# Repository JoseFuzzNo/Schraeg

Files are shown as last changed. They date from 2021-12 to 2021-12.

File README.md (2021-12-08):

# Schräg

Schräg is an 8HP multimode filter module for the eurorack format, based off the [Bastl Cinnamon](https://bastl-instruments.com/eurorack/modules/cinnamon).

This is a rework of the original [Schräg](https://github.com/barnabywalters/Schraeg) by Barnaby Walters.

<p align="center">
    
</p>

## Quick links

* [Schematic](pcb/schraeg.pdf)
* [Gerbers](gerbers/schraeg-gerbers-0.4.zip)
* [BOM](bom/schraeg_BOM.xlsx)
* [Schräg on ModularGrid](https://www.modulargrid.net/e/other-unknown-f1no5-schraeg)

## Features

Schräg is effectively a repackaged Bastl Cinnamon:

* Multimode filter with independent outputs (2-pole LP, 2-pole HP, 1-pole BP)
* V/oct input
* Self-resonates for use as a sine oscillator
* Input with an attenuator and 5x gain switch
* Two character switches for altering the resonance tracking
* All-SMD construction in a DIY-friendly format, with 0603 handsoldering footprints, all components on the back of the circuit board
* Built mostly using standard and easily-available components

with a few modifications:

* Larger 8HP form factor, allowing for a big juicy cutoff knob and larger character and gain switches
* Voltage control over resonance, through an attenuverter
* FM input through an attenuverter, which works as a pitch fine-tune control with nothing patched
* A bi-directional power connector, with polyfuses
* An Interactive BOM (`bom/schraeg_iBOM.html` once you’ve cloned the repo locally) to aid in part placement
* Schematics and PCB laid out using KiCAD

The additional functionality is achieved with a minimum of extra components, thanks to the two unused VCA cells in the original design.

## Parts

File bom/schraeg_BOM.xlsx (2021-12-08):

SCHRÄG, v0.4.0
Designator | Description | Package | Specs | Qty | Value | Manufacturer | Reference | Ref. Mouser
SMD Parts: 84 pcs
C3,C9 | Capacitor, ceramic | 0603 |  | 2 | 100p | Yageo | CC603GPNPO9BN101 | 603-CC603GPNPO9BN101
C10,C11,C13 | Capacitor, ceramic | 0603 |  | 3 | 220p | Yageo | CC603JRX7R9BB221 | 603-CC603JRX7R9BB221
C1,C7,C8,C12 | Capacitor, ceramic | 0603 |  | 4 | 560p | Yageo | CC603JRNPO8BN561 | 603-CC603JRNPO8BN561
C14,C15,C19,C20,C21,C22,C23,C24,C25,C26,C27,C28 | Capacitor, ceramic | 0603 | >= 25V | 10 | 100n | Yageo | CC0603MR9BB104 | 603-CC0603MR9BB104
C2,C4,C5,C6 | Capacitor, electrolytic | 5x4.5 |  | 4 | 10u | Panasonic | EEE-FC1V100R | 667-EEE-FC1V100R
C16,C17 | Capacitor, electrolytic | 6.3x5.4 | >= 25V | 2 | 22u | Panasonic | EEE-FC1E220AP | 667-EEE-FC1E220AP
D1,D2,D4 | Diode, general purpose | SOD-123 |  | 3 |  | Diodes Inc | 1N4148W-7-F | 621-1N4148W-F
D3 | Diode, zener | SOT-23-3 | 5V | 1 |  | Nexperia | PLVA650A,215 | 771-PLVA650A-T/R
D5 | Full bridge rectifier | SO-4 |  | 1 |  | OnSemi | MB1S | 512-MB1S
F1,F2 | PTC Fuse | 1206 |  | 2 |  | Bourns | MF-NSMF050-2 | 652-MF-NSMF050-2
R44 | Resistor, 1% | 0603 |  | 1 | 220R | Panasonic | ERJ-3EKF2200V | 667-ERJ-3EKF2200V
R15,R30,R32,R39 | Resistor, 1% | 0603 |  | 4 | 470R | Panasonic | ERJ-3EKF4700V | 667-ERJ-3EKF4700V
R23,R24,R25 | Resistor, 1% | 0603 |  | 3 | 1K | Panasonic | ERJ-3EKF1001V | 667-ERJ-3EKF1001V
R41 | Resistor, 1% | 0603 |  | 1 | 1K5 | Panasonic | ERJ-3EKF1501V | 667-ERJ-3EKF1501V
R21 | Resistor, 1% | 0603 |  | 1 | 10K | Panasonic | ERJ-3EKF1002V | 667-ERJ-3EKF1002V
R14,R40 | Resistor, 1% | 0603 |  | 2 | 15K | Panasonic | ERJ-3EKF1502V | 667-ERJ-3EKF1502V
R18 | Resistor, 1% | 0603 |  | 1 | 22K | Panasonic | ERJ-3EKF2202V | 667-ERJ-3EKF2202V
R27,R28,R29,R31,R33,R34,R35,R36,R38 | Resistor, 1% | 0603 |  | 9 | 33K | Panasonic | ERJ-3EKF3302V | 667-ERJ-3EKF3302V
R19,R22 | Resistor, 1% | 0603 |  | 2 | 47K | Panasonic | ERJ-3EKF4702V | 667-ERJ-3EKF4702V
R8 | Resistor, 1% | 0603 |  | 1 | 56K | Panasonic | ERJ-3EKF5602V | 667-ERJ-3EKF5602V
R1,R2,R3,R4,R5,R6,R7,R9,R10,R13,R16,R17,R20,R37,R42,R48,R49 | Resistor, 1% | 0603 |  | 17 | 100K | Panasonic | ERJ-3EKF1003V | 667-ERJ-3EKF1003V
R12 | Resistor, 1% | 0603 |  | 1 | 220K | Panasonic | ERJ-3EKF2203V | 667-ERJ-3EKF2203V
R26 | Resistor, 1% | 0603 |  | 1 | 330K | Panasonic | ERJ-3EKF3303V | 667-ERJ-3EKF3303V
R43 | Resistor, 1% | 0603 |  | 1 | 470K | Panasonic | ERJ-3EKF4703V | 667-ERJ-3EKF4703V
R11 | Resistor, 1% | 0603 |  | 1 | 2M2 | Panasonic | ERJ-3EKF2204V | 667-ERJ-3EKF2204V
U1,U2,U4,U5 | Quad op-amp | TSSOP-14 |  | 4 |  | Texas Instruments | TL074CPWR | 595-TL074CPWR
U3 | Quad VCA | SOIC-16 |  | 1 |  | Cool Audio | V2164
U6 | Single op-amp | SOT-23-5 |  | 1 |  | Texas Instruments | LM321MFX/NOPB | 926-LM321MFX/NOPB
THT Parts: 20 pcs
D6 | LED, red, 5mm | T-1 3/4 |  | 1 |  | Kingbright | WP483IDT | 604-WP483IDT
J1,J2,J3,J4,J5,J6,J7 | Vertical jack connector |  |  | 7 |  | QingPu | PJ398SM
J8 | 2x5 male header, 2.54mm pitch |  |  | 1 |  | Amphenol FCI | 67996-410HLF | 649-67996-410HLF
RV1,RV2,RV3,RV4 | 100K linear pot, 25mm shaft with marker |  |  | 4 | 100K | Song Huei
RV5 | 100K linear pot, 15mm shaft |  |  | 1 | 100KB | Alpha
RV6 | Multiturn trimmer pot |  |  | 1 | 100K | Bourns | 3266Y-1-104LF | 652-3266Y-1-104LF
RV7 | Multiturn trimmer pot |  |  | 1 | 5K | Bourns | 3266Y-1-502LF | 652-3266Y-1-502LF
RV8 | Multiturn trimmer pot |  |  | 1 | 250K | Bourns | 3266Y-1-254LF | 652-3266Y-1-254LF
SW1,SW2,SW3 | Slide switch SPDT |  |  | 3 |  | NKK Switches | CS12ANW03 | 633-CS12ANW03

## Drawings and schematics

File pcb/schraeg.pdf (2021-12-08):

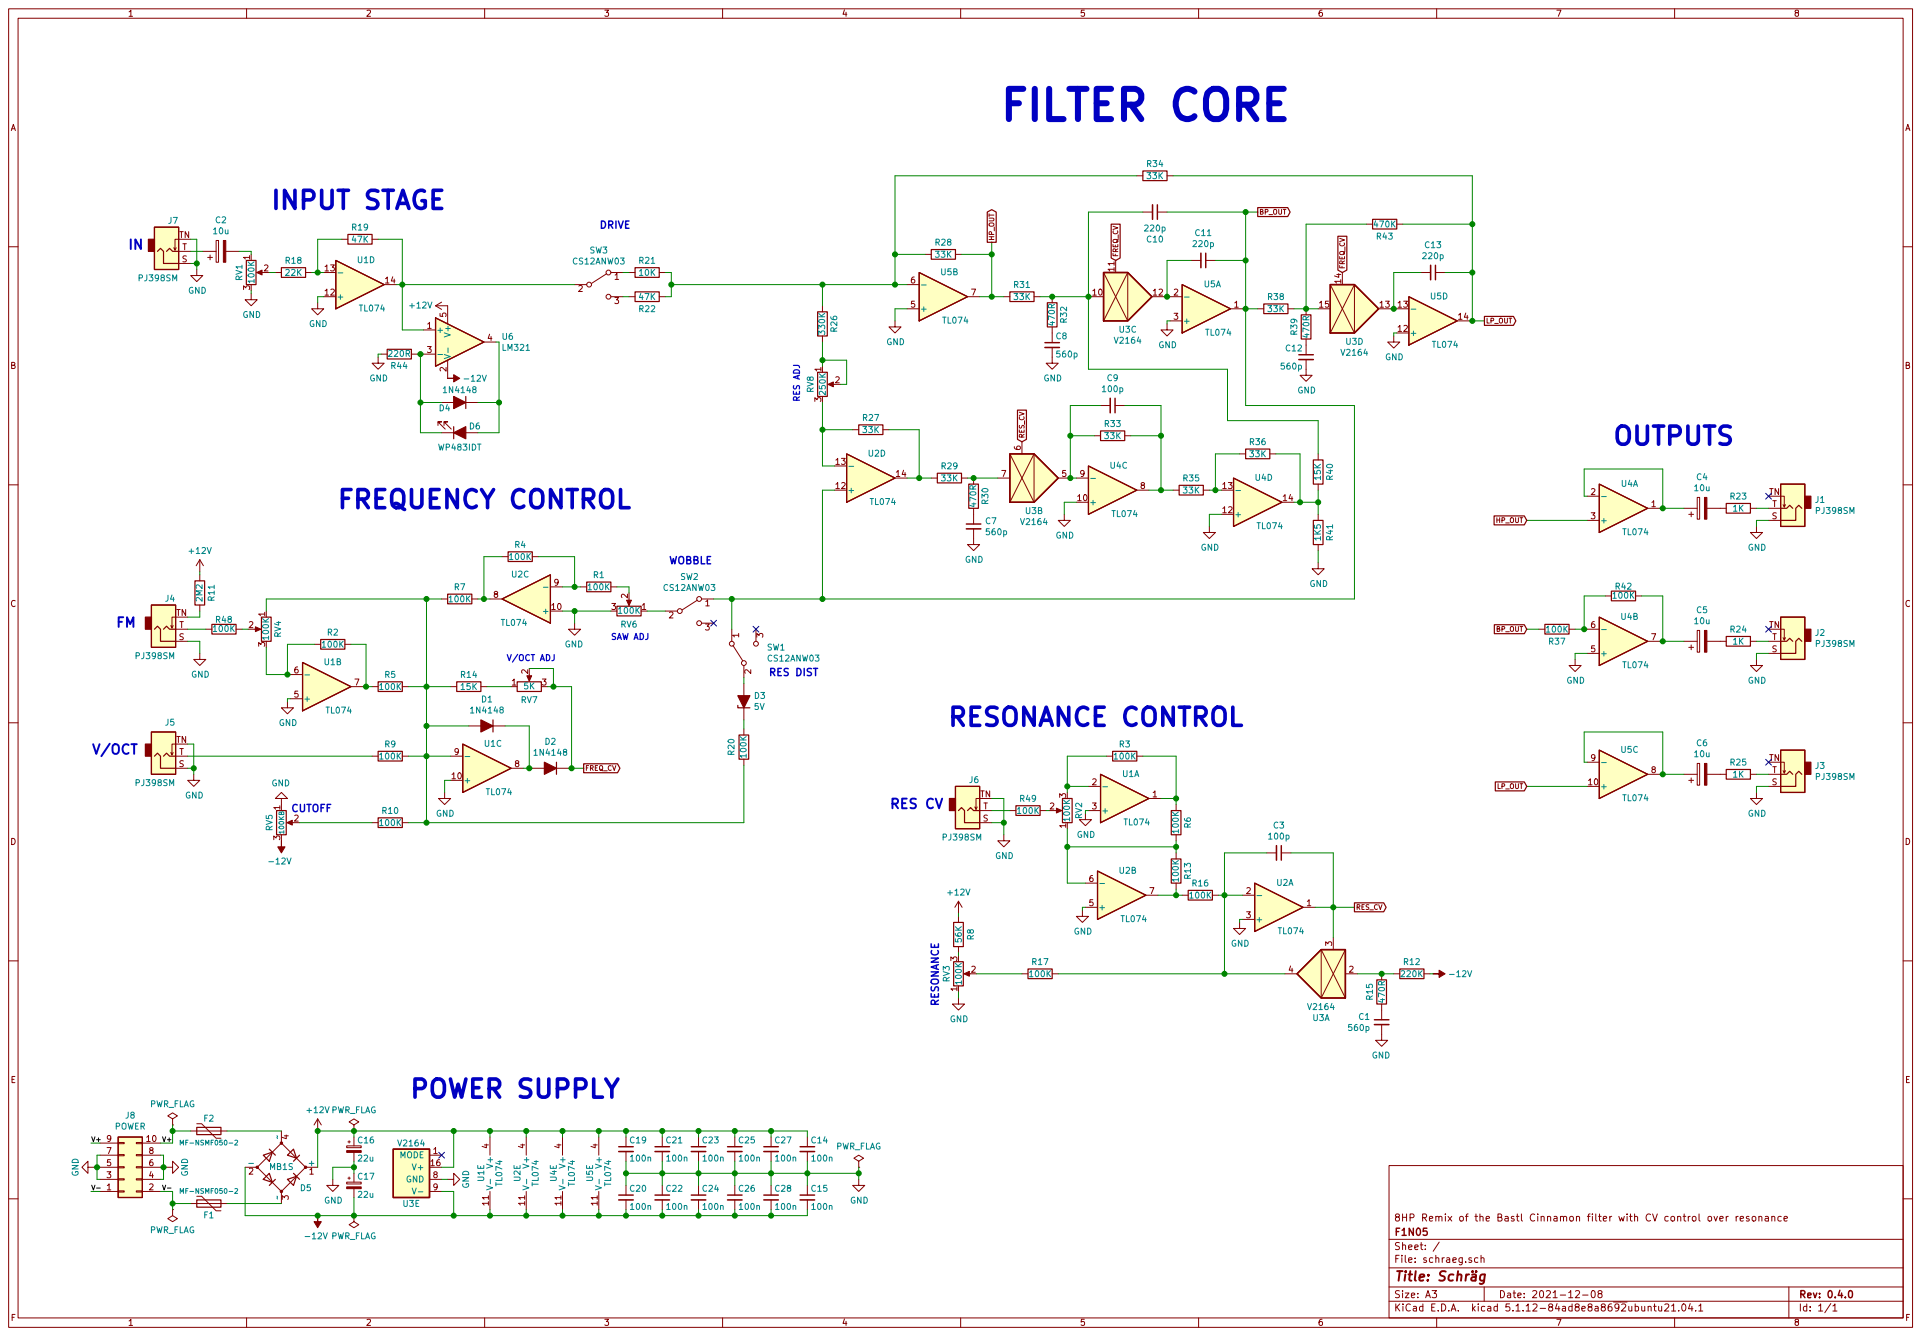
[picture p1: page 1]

8HP Remix of the Bastl Cinnamon filter with CV control over resonance
File: schraeg.sch Sheet: / F1N05

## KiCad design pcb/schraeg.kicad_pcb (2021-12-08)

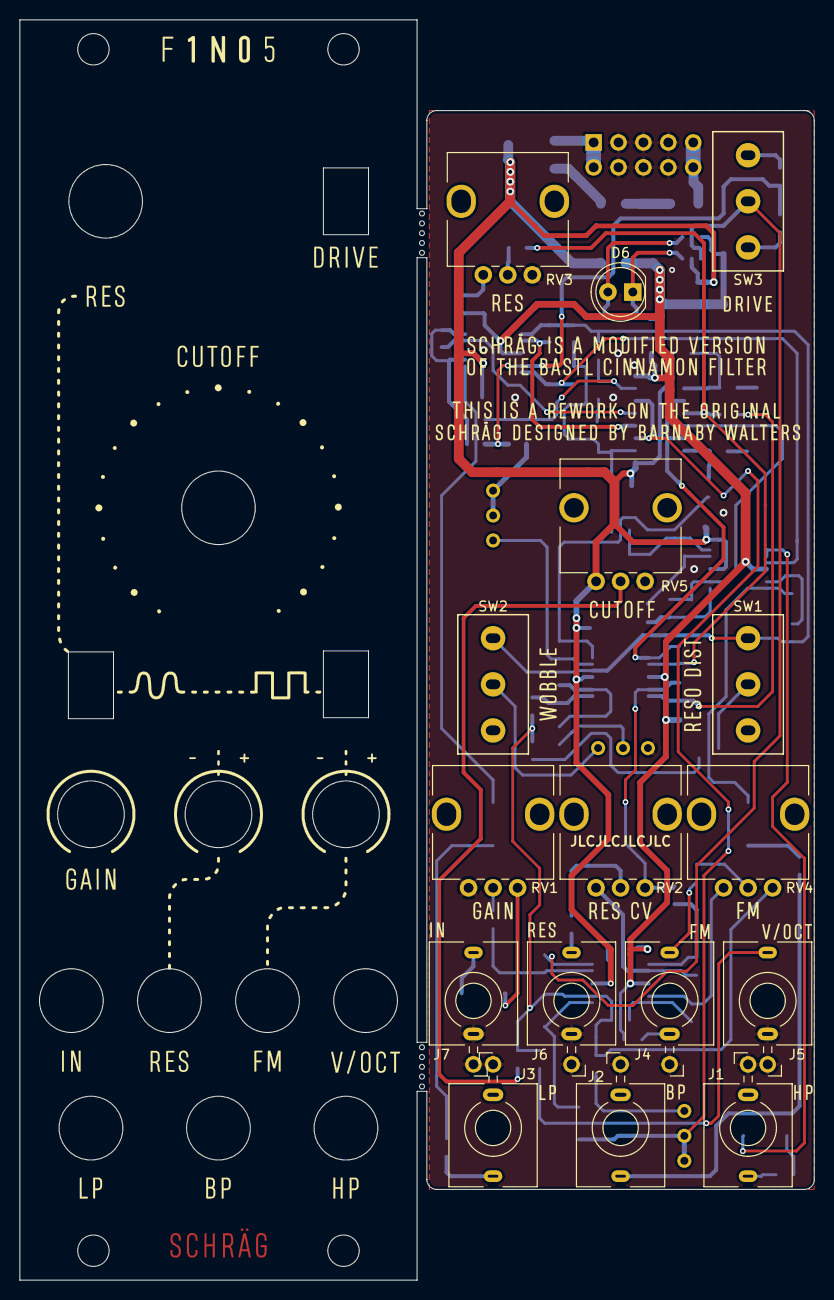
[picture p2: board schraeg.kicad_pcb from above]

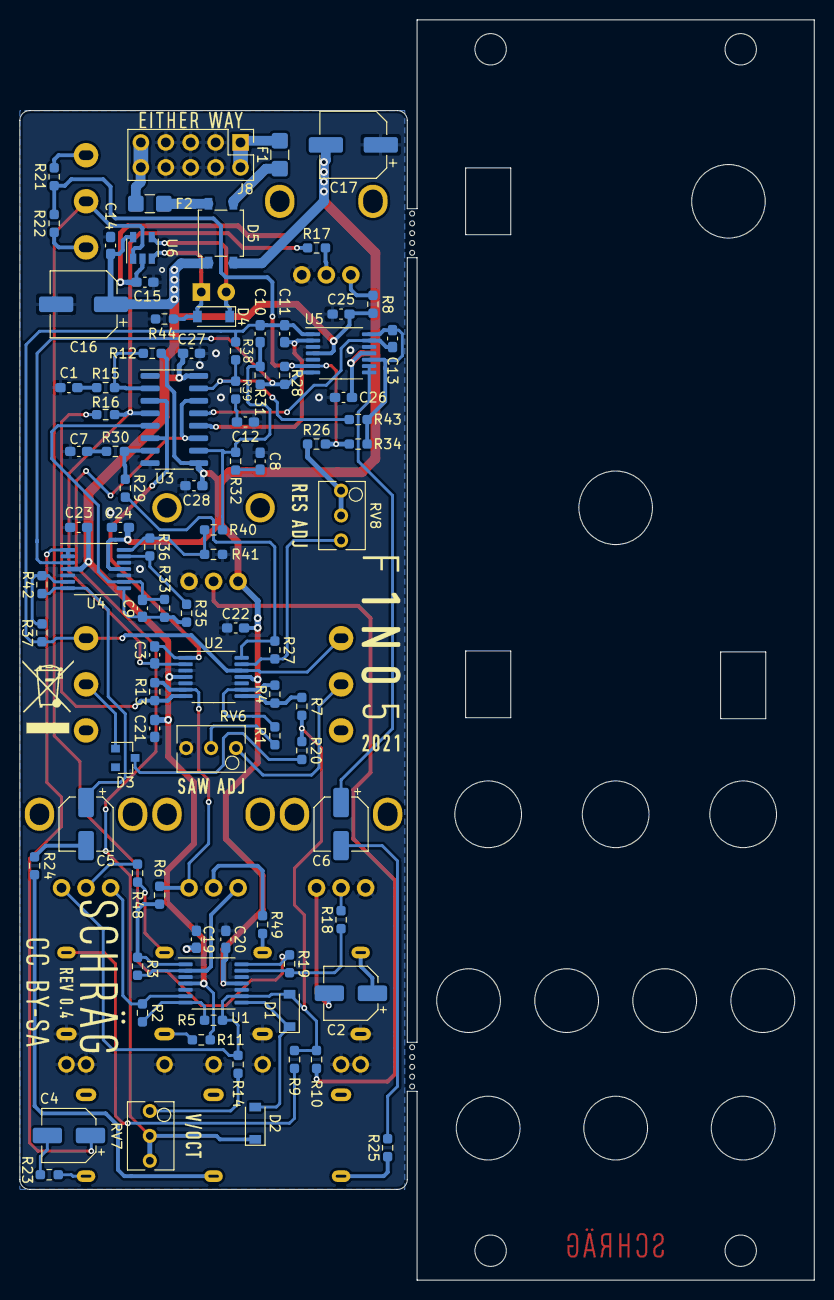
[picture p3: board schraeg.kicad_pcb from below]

Board: 2 copper layers, 81.0 x 128.5 mm, 106 parts (90 on the bottom side), 74 nets.

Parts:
C1, C7, C8, C12: 560p; C_0603_1608Metric_Pad1.08x0.95mm_HandSolder
C2, C4, C5, C6: 10u; CP_Elec_5x4.5
C3, C9: 100p; C_0603_1608Metric_Pad1.08x0.95mm_HandSolder
C10, C11, C13: 220p; C_0603_1608Metric_Pad1.08x0.95mm_HandSolder
C14, C15, C19, C20, C21, C22, C23, C24, C25, C26, C27, C28: 100n; C_0603_1608Metric_Pad1.08x0.95mm_HandSolder
C16, C17: 22u; CP_Elec_6.3x5.4
D1, D2, D4: 1N4148; D_SOD-123
D3: 5V; D_SOT-23_ANK
D5: MB1S; SO-4_4.4x4.3mm_P2.54mm
D6: WP483IDT; LED_D5.0mm
F1, F2: MF-NSMF050-2; Fuse_1206_3216Metric_Castellated
J1, J2, J3, J4, J5, J6, J7: PJ398SM; Jack_3.5mm_QingPu_WQP-PJ398SM_Vertical_CircularHoles
J8: POWER; PinHeader_2x05_P2.54mm_Vertical
R1, R2, R3, R4, R5, R6, R7, R9, R10, R13, R16, R17, R20, R37, R42, R48, R49: 100K; R_0603_1608Metric_Pad0.98x0.95mm_HandSolder
R8: 56K; R_0603_1608Metric_Pad0.98x0.95mm_HandSolder
R11: 2M2; R_0603_1608Metric_Pad0.98x0.95mm_HandSolder
R12: 220K; R_0603_1608Metric_Pad0.98x0.95mm_HandSolder
R14, R40: 15K; R_0603_1608Metric_Pad0.98x0.95mm_HandSolder
R15, R30, R32, R39: 470R; R_0603_1608Metric_Pad0.98x0.95mm_HandSolder
R18: 22K; R_0603_1608Metric_Pad0.98x0.95mm_HandSolder
R19, R22: 47K; R_0603_1608Metric_Pad0.98x0.95mm_HandSolder
R21: 10K; R_0603_1608Metric_Pad0.98x0.95mm_HandSolder
R23, R24, R25: 1K; R_0603_1608Metric_Pad0.98x0.95mm_HandSolder
R26: 330K; R_0603_1608Metric_Pad0.98x0.95mm_HandSolder
R27, R28, R29, R31, R33, R34, R35, R36, R38: 33K; R_0603_1608Metric_Pad0.98x0.95mm_HandSolder
R41: 1K5; R_0603_1608Metric_Pad0.98x0.95mm_HandSolder
R43: 470K; R_0603_1608Metric_Pad0.98x0.95mm_HandSolder
R44: 220R; R_0603_1608Metric_Pad0.98x0.95mm_HandSolder
RV1, RV2, RV3, RV4: 100K; Potentiometer_Trimmer_9mm_Vertical
RV5: 100KB; Potentiometer_Alps-Alpha-Bourns_Single_Vertical
RV6: 100K; Potentiometer_Bourns_3266Y_Vertical
RV7: 5K; Potentiometer_Bourns_3266Y_Vertical
RV8: 250K; Potentiometer_Bourns_3266Y_Vertical
SW1, SW2, SW3: CS12ANW03; SW_NKK_CS1xA
U1, U2, U4, U5: TL074; TSSOP-14_4.4x5mm_P0.65mm
U3: V2164; SOIC-16_3.9x9.9mm_P1.27mm
U6: LM321; SOT-23-5

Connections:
+12V: C14.1, C16.1, C19.1, C21.1, C23.1, C25.1, C27.1, D5.1, R8.1, R11.2, U1.4, U2.4, U3.16, U4.4, U5.4, U6.5
-12V: C15.2, C17.2, C20.2, C22.2, C24.2, C26.2, C28.2, D5.2, R12.2, RV5.3, U1.11, U2.11, U3.9, U4.11, U5.11, U6.2
/V+: F2.2, J8.9, J8.10
/V-: F1.2, J8.1, J8.2
BP_OUT: C10.1, C11.1, R37.2, R38.2, SW1.1, SW2.1, U2.12, U5.1
FREQ_CV: D2.1, RV7.2, RV7.3, U3.11, U3.14
GND: C1.2, C7.2, C8.2, C12.2, C14.2, C15.1, C16.2, C17.1, C19.2, C20.1, C21.2, C22.1, C23.2, C24.1, C25.2, C26.1, C27.2, C28.1, J1.S, J2.S, J3.S, J4.S, J5.S, J5.TN, J6.S, J6.TN, J7.S, J7.TN, J8.3, J8.4, J8.5, J8.6, J8.7, J8.8, R41.1, R44.1, RV1.3, RV3.1, RV5.1, RV6.3, U1.3, U1.5, U1.10, U1.12, U2.3, U2.5, U2.10, U3.8, U4.5, U4.10, U4.12, U5.3, U5.5, U5.12
HP_OUT: R28.1, R31.2, U4.3, U5.7
LP_OUT: C13.1, R34.1, R43.1, U5.10, U5.14
unnamed: C1.1, R15.1
unnamed: C2.1, J7.T
unnamed: C2.2, RV1.1
unnamed: C3.2, R16.1, R17.1, U2.2, U3.4
unnamed: C4.1, U4.1, U4.2
unnamed: C4.2, R23.2
unnamed: C5.1, R42.1, U4.7
unnamed: C5.2, R24.2
unnamed: C6.1, U5.8, U5.9
unnamed: C6.2, R25.2
unnamed: C7.1, R30.1
unnamed: C8.1, R32.1
unnamed: C9.1, R33.1, R35.2, U4.8
unnamed: C9.2, R33.2, U3.5, U4.9
unnamed: C10.2, R31.1, R32.2, R40.2, U3.10
unnamed: C11.2, U3.12, U5.2
unnamed: C12.1, R39.1
unnamed: C13.2, U3.13, U5.13
unnamed: D1.1, D2.2, U1.8
unnamed: D1.2, R5.1, R7.1, R9.1, R10.1, R14.2, R20.1, RV4.1, U1.9
unnamed: D3.1, R20.2
unnamed: D3.2, SW1.2
unnamed: D4.1, D6.2, U6.4
unnamed: D4.2, D6.1, R44.2, U6.3
unnamed: D5.3, F1.1
unnamed: D5.4, F2.1
unnamed: J1.T, R23.1
unnamed: J2.T, R24.1
unnamed: J3.T, R25.1
unnamed: J4.T, R48.1
unnamed: J4.TN, R11.1
unnamed: J5.T, R9.2
unnamed: J6.T, R49.2
unnamed: R1.1, R4.2, U2.9
unnamed: R1.2, RV6.2
unnamed: R2.1, R5.2, U1.7
unnamed: R2.2, RV4.3, U1.6
unnamed: R3.1, R6.1, U1.1
unnamed: R3.2, RV2.3, U1.2
unnamed: R4.1, R7.2, U2.8
unnamed: R8.2, RV3.3
unnamed: R10.2, RV5.2
unnamed: R12.1, R15.2, U3.2
unnamed: R13.1, R16.2, U2.7
unnamed: R6.2, R13.2, RV2.1, U2.6
unnamed: R14.1, RV7.1
unnamed: R17.2, RV3.2
unnamed: R18.1, R19.2, U1.13
unnamed: R18.2, RV1.2
unnamed: R19.1, SW3.2, U1.14, U6.1
unnamed: R21.1, R22.1, R26.2, R28.2, R34.2, U5.6
unnamed: R21.2, SW3.1
unnamed: R22.2, SW3.3
unnamed: R26.1, RV8.1, RV8.2
unnamed: R27.1, R29.2, U2.14
unnamed: R27.2, RV8.3, U2.13
unnamed: R29.1, R30.2, U3.7
unnamed: R35.1, R36.2, U4.13
unnamed: R36.1, R40.1, R41.2, U4.14
unnamed: R37.1, R42.2, U4.6
unnamed: R38.1, R39.2, R43.2, U3.15
unnamed: R48.2, RV4.2
unnamed: R49.1, RV2.2
unnamed: RV6.1, SW2.2
RES_CV: C3.1, U2.1, U3.3, U3.6

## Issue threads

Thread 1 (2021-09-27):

Fix FM Input range

JoseFuzzNo, 2021-09-27:

JoseFuzzNo, 2021-09-27:
Removed R8 because it was added to R5 or R48 and made a 200K gain resistor. Also R2, R5, and R48 are changed to 47K because we want a similar output swing that the cutoff control, that is 5V * (15K/47K).

Closed 2021-09-27.

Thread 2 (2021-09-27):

Fix RES CV range

JoseFuzzNo, 2021-09-27:

JoseFuzzNo, 2021-09-27:
As with the FM attenuverter, R11 was making the gain of the stage half of what it should. Removing that resistor we obtain a swing of -5 to 5V given a 5V input.

Closed 2021-09-27.

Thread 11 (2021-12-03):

LED indicator is not connected properly

JoseFuzzNo, 2021-12-03:
The LED stage is connected to the inverting input of U5B which is at 0V. This should be connected to the output of the input stage (U1D), before the gain resistor.

Closed 2021-12-08.

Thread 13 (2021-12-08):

FM range too wide

JoseFuzzNo, 2021-12-08:
FM range should be the same as V/OCT. Changing the 3 47K resistors for 100K solves the issue.

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

Closed 2021-12-08.

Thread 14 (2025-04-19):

Resonance control seems to not be under control

extremenerble, 2025-04-19:
Hello, first thanks for your work and publishing this design. Shot in the dark here that maybe you can point me in the right direction with some build help.

I put this module together and everything is working except the resonance is out of control. The Res knob doesn't really function, there's lots of resonance all the time. It seems to slightly change the character of the resonance with various combinations of the switches, but I can not take out resonance entirely. I'm using alpha pots for all the front panel controls (instead of tall trimmers), but that shouldn't have an effect, they're all  B100k.

I've verified continuity for all the components in the Resonance Control section of your schematic. The VCA chip is an SSI2164 sourced from Thonk. I have a spare 2164 but I haven't swapped it out yet.

Any ideas would be greatly appreciated!

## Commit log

2021-09-26 Added gitignore with kicad files
2021-09-26 Corrected alignment between panel and pcb, changed to slide switches, trimpot for resonance (leaves more space for cutoff) and new panel design.
    [Schraeg BOM.csv, Schraeg.kicad_pcb, Schraeg.sch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]
2021-09-26 Changed power symbol to generic connector
    [Schraeg.kicad_pcb, Schraeg.sch, power_supply.sch]
2021-09-26 V2164 symbol in a new library to avoid missing dependencies.
    [Schraeg.kicad_pcb, Schraeg.sch, filter_core.sch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]
2021-09-26 Cleaning and organizing the repo.
    [Schraeg Panel Graphics 40.64 x 128.5.dxf, Schraeg Panel Graphics.dxf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]
2021-09-27 #1 - Corrected FM atennuverter
    [Schraeg.kicad_pcb, Schraeg.sch]
2021-09-27 #2 - Corrected resonance attenuverter
    [Schraeg.kicad_pcb, Schraeg.sch]
2021-09-27 Changed paths to use Kicad variables
    [Schraeg.kicad_pcb]
2021-09-27 Consolidate names
    [filter_core.sch, power_supply.sch, schraeg.kicad_pcb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]
2021-09-27 #4 - Added mouser references
    [filter_core.sch, power_supply.sch, schraeg.kicad_pcb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]
2021-09-28 Tidy up
    [filter_core.sch, power_supply.sch, schraeg.kicad_pcb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]
2021-09-28 #5 - Removed 0.16V normalization to FM input.
    [schraeg.kicad_pcb, schraeg.sch]
2021-09-29 #4 - Added BOM with mouser references.
    [schraeg_BOM.csv, schraeg_BOM.xlsx]
2021-09-30 #6 - Replaced the 5V reference with a resistor divider. It should give a voltage of 5.1V.
    [schraeg.kicad_pcb, schraeg.sch, schraeg_BOM.xlsx]
2021-09-30 #7 - Removed the -5V reference. Changed R12 to have the same effect as before with -12V (-10.8V after the rectifier).
    [schraeg.kicad_pcb, schraeg.sch, schraeg_BOM.xlsx]
2021-10-04 New pcb distribution
    [schraeg.kicad_pcb, schraeg.sch, schraeg_BOM.xlsx]
2021-10-05 PCB Layout finished.
    [schraeg.kicad_pcb, schraeg.sch]
2021-10-05 BOM updated with smaller packages
    [schraeg_BOM.xlsx]
2021-10-05 Panel design on kicad and iBOM updated.
    [schraeg.kicad_pcb]
2021-10-06 Added silkscreen on PCB
    [schraeg.kicad_pcb]
2021-10-06 #8 - Added back the FM normalization. This time with a bit more than 1 OCT range.
    [schraeg.kicad_pcb, schraeg.sch, schraeg_BOM.xlsx]
2021-10-06 Version 0.3.0
    [schraeg.kicad_pcb, schraeg.sch, schraeg_BOM.xlsx]
2021-10-06 Update PDF schematic
2021-10-07 #9 - Added LED input indicator.
    [schraeg.kicad_pcb, schraeg.sch, schraeg_BOM.xlsx]
2021-10-12 #10 - Corrected rectifier orientation.
    [schraeg.kicad_pcb, schraeg.sch, schraeg_BOM.xlsx]
2021-10-15 Corrected PTC footprint. From 1206 to 0805
    [schraeg.kicad_pcb, schraeg.sch, schraeg_BOM.xlsx]
2021-10-15 Removed copper on the panel mounting holes
    [schraeg.kicad_pcb]
2021-10-15 Version 0.3.1
    [schraeg.kicad_pcb, schraeg.sch, schraeg_BOM.xlsx]
2021-10-22 Only one row of mouse bites
    [schraeg.kicad_pcb]
2021-10-22 Version 0.3.2
    [schraeg.kicad_pcb, schraeg.sch, schraeg_BOM.xlsx]
2021-12-08 #13 - Halved FM input range
    [schraeg.kicad_pcb, schraeg.sch, schraeg_BOM.xlsx]
2021-12-08 #12 - Changed fuse footprint to 1206
    [schraeg.kicad_pcb, schraeg.sch, schraeg_BOM.xlsx]
2021-12-08 #11 - FIX: LED indicator stage connected to the output of the input stage.
    [schraeg.kicad_pcb, schraeg.sch, schraeg_BOM.xlsx]
2021-12-08 Version 0.4.0
    [schraeg.kicad_pcb, schraeg.sch, schraeg_BOM.xlsx]
2021-12-08 Fix gerber link on README
